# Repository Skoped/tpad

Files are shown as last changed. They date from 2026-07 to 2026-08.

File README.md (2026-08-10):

```                                                                                                                                           __                              .___
_/  |_          ___________     __| _/
\   __\  ______ \____ \__  \   / __ | 
 |  |   /_____/ |  |_> > __ \_/ /_/ | 
 |__|           |   __(____  /\____ | 
                |__|       \/      \/                                                                                                                                            
```
<sub> just a hackpad but better </sub>

so im made this macropad as a challenge, and it did NOT go well.
made this repo to show yall my progress   <sub> (its only made to submit this project) </sub>    i also couldnt make the knob work because i originally had the wrong 3d model for the rotary encoder.. (i made the knob :D)
anyways ignore all that,
# features.
it has 6 keys, one of them acting as a gateway to the second layer. so it technically has the usage of 10 keys, which i put from f1 to f10 because i use a 60% keyboard and the f-row doesnt always work for some reason.
it has a knob that acts as a way to decrease/increase volume, and when that knob is toggled, it acts as a way to decrease/increase brightness.
the screen currently only shows what layer your mini keyboard is on, pretty useless but im gonna work on another usecase.
# the pcb.
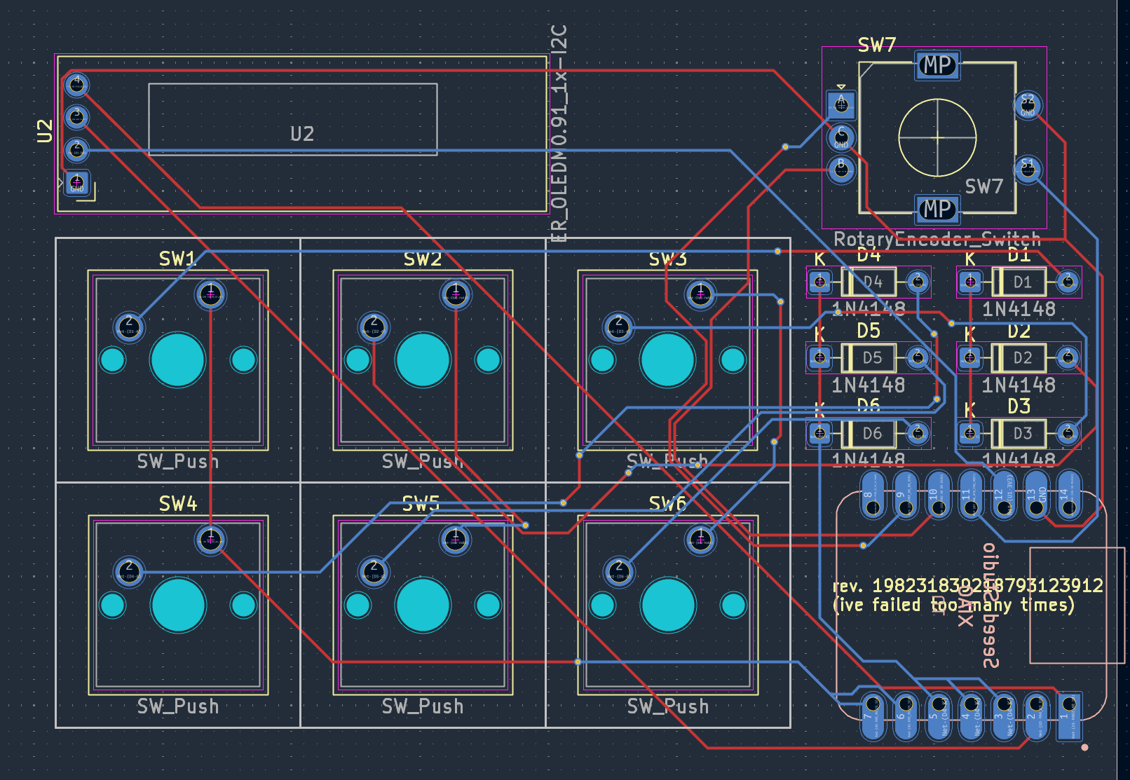
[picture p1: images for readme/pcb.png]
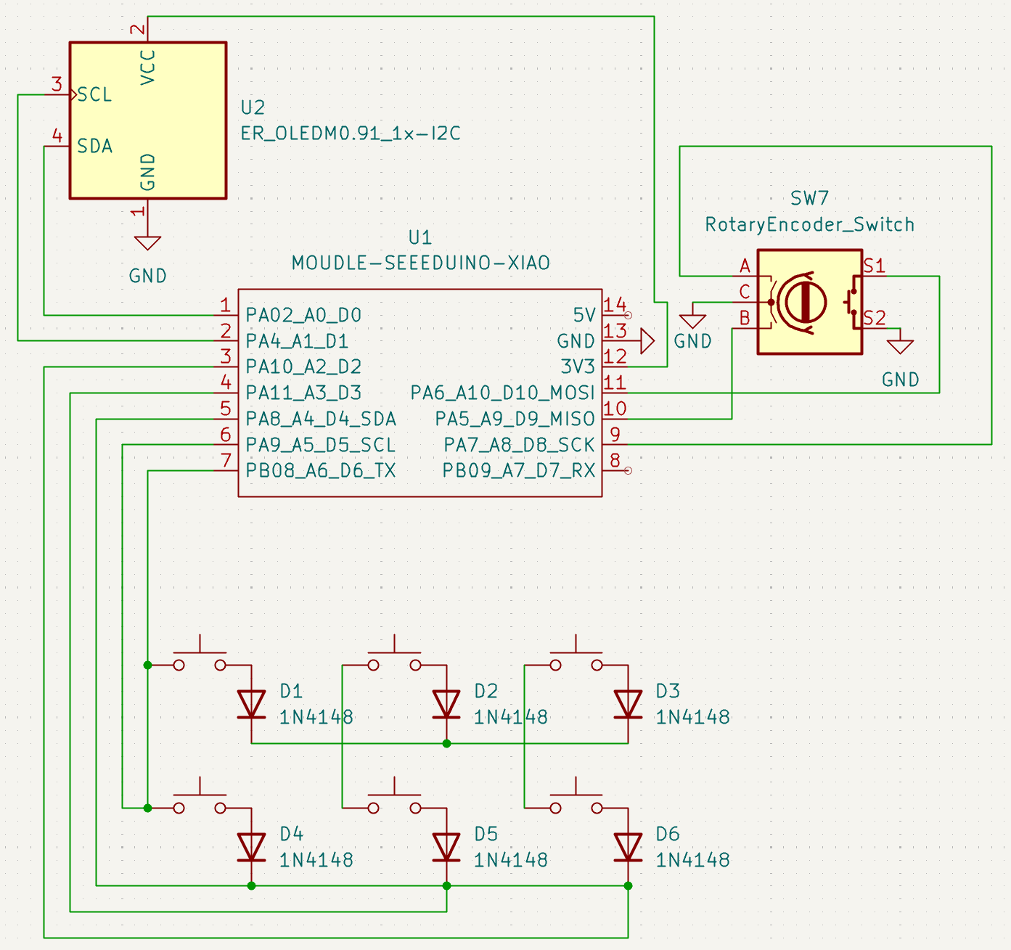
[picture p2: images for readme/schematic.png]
<figure> <figcaption>the pcb</figcaption>  </figure> <figure> <figcaption>the schematics</figcaption>  </figure>

i made this thing using kicad and tried to make it as tidy as possible which obviously i failed at that. this was probably the easiest part but i kept going back to it because i really didnt do it correctly at first.
# the case.
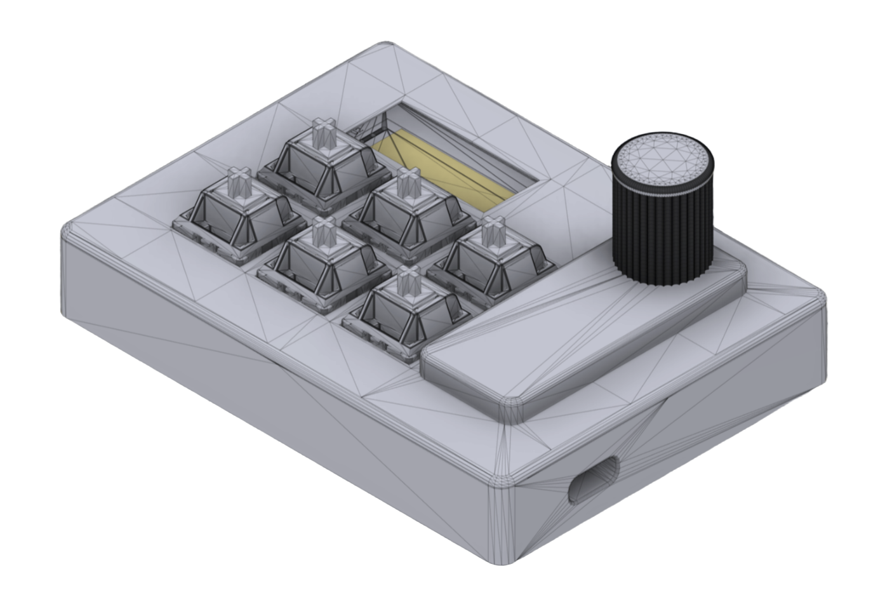
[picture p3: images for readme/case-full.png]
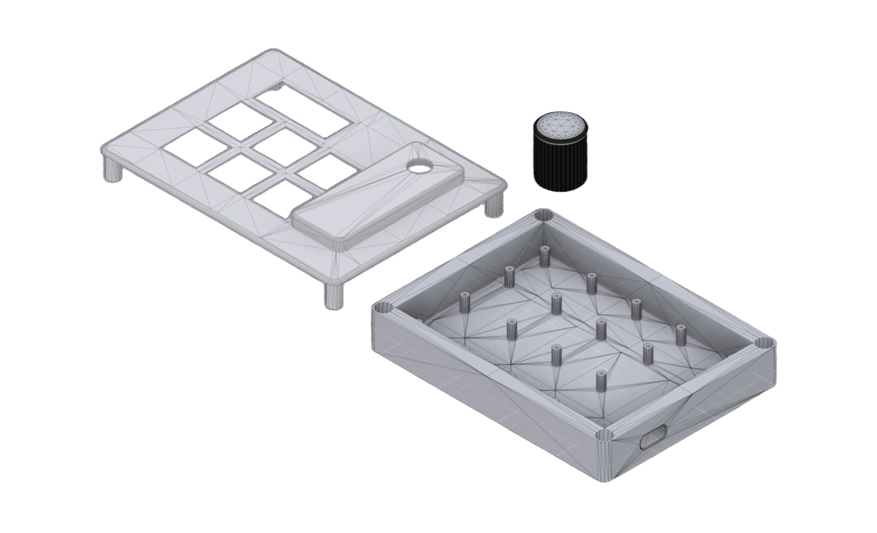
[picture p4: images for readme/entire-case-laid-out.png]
<figure> <figcaption>case put together</figcaption>  </figure> <figure> <figcaption>case laid out</figcaption>  </figure>

the case consists of 2 parts, the top and the bottom. i made it so the screws can screw in from the bottom, so that they can be hidden. the top has some columns coming out of it so the screw can screw the screw in the columns through the holes in the bottom layer, holding the two parts together.
worst part of this entire thing, fusion360 was too hard and i decided to experiment a bit with different software. i went on an ipad and found the absolute best app for this (very expensive so i used the trial :D). the app is shapr3d, i couldnt use fusion mostly because im using it on a pc with no touchscreen, making it harder to design what i wanted exactly.
# the firmware.
wasnt hard, kmk is easy and has alot of documentation to help with it. hopefully i can someday be good enough at programming to make a gui interface for remapping the keys. i only used layers to add about double the functionality to the keyboard (sixth button changes the entire keymap, and when the knob is pressed it changes brightness instead of volume, i just thought it was a cool way to make this different)
# BOM.
6x Cherry MX Switches

6x through-hole 1N4148 diodes

1x Seeed Studios XIAO RP2040

1x 0.91" OLED display SSD1306

1x EC11 rotary encoder

4x Keycaps

4x M3x5x4 headset inserts

4x M3x16mm screws

1x Case (2 part build, top and bottom)

### dont recommend this but will definitely do it again. 0/10
 *pcb and schematics made in kicad, case made in shapr3d, and the firmware made using kmk*

 this is not over, the screen basically doesnt do anything (just shows current keyboard layer) currently so im looking forward to edit its usecase. i also really wanna make that gui app for remapping everything :D

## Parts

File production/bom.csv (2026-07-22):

Designator | Footprint | Quantity | Value | LCSC Part #
D1, D2, D3, D4, D5, D6 | D_DO-35_SOD27_P7.62mm_Horizontal | 6 | 1N4148
SW1, SW2, SW3, SW4, SW5, SW6 | SW_Cherry_MX_1.00u_PCB | 6 | SW_Push
SW7 | RotaryEncoder_Alps_EC11E-Switch_Vertical_H20mm | 1 | RotaryEncoder_Switch
U1 | XIAO-Generic-Hybrid-14P-2.54-21X17.8MM | 1 | MOUDLE-SEEEDUINO-XIAO
U2 | ER_OLEDM0.91_1x-I2C | 1 | ER_OLEDM0.91_1x-I2C

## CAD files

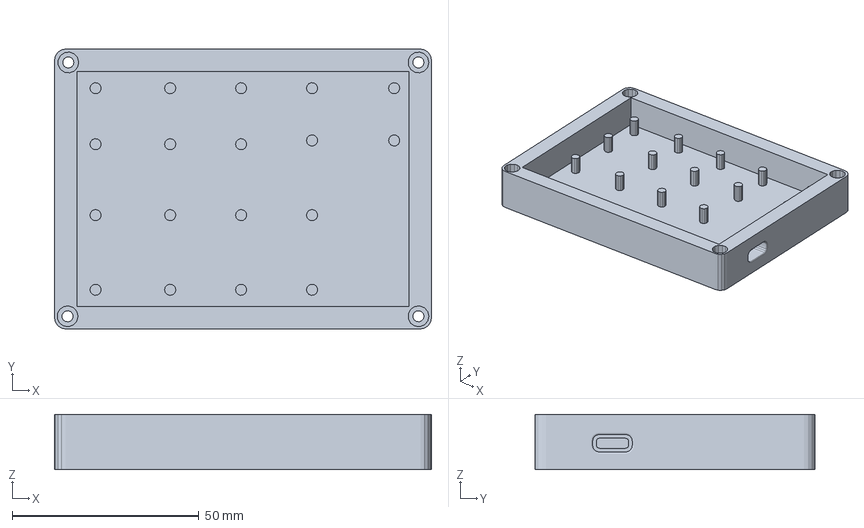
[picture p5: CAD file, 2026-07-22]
CAD/tpad-case.3mf
101.0 x 75.0 x 14.8 mm

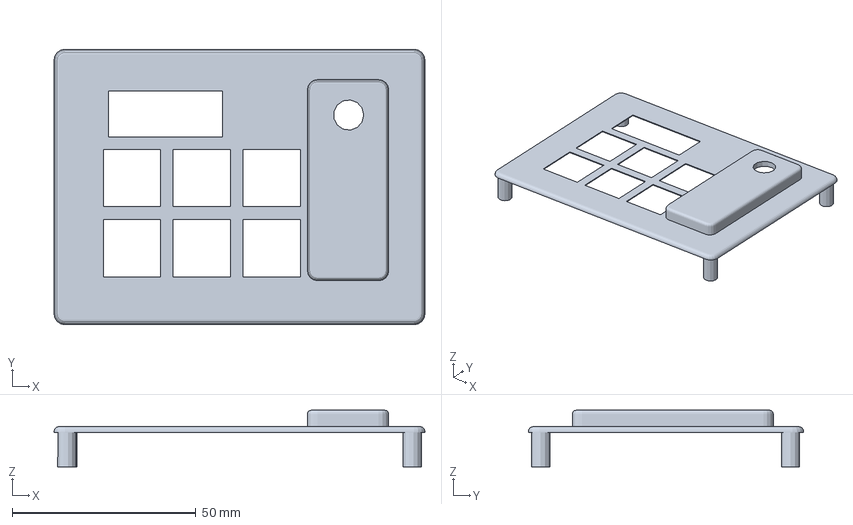
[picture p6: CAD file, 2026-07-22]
CAD/tpad-top.3mf
101.0 x 75.0 x 15.4 mm

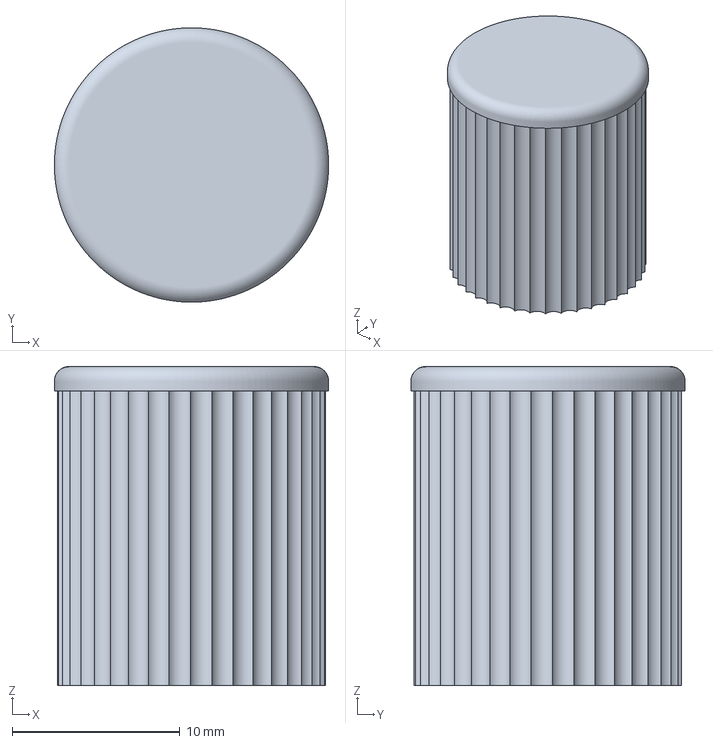
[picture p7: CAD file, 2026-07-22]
CAD/tpad-knob.3mf
16.3 x 16.3 x 19.0 mm

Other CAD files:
production/bottom.stl
production/top.stl

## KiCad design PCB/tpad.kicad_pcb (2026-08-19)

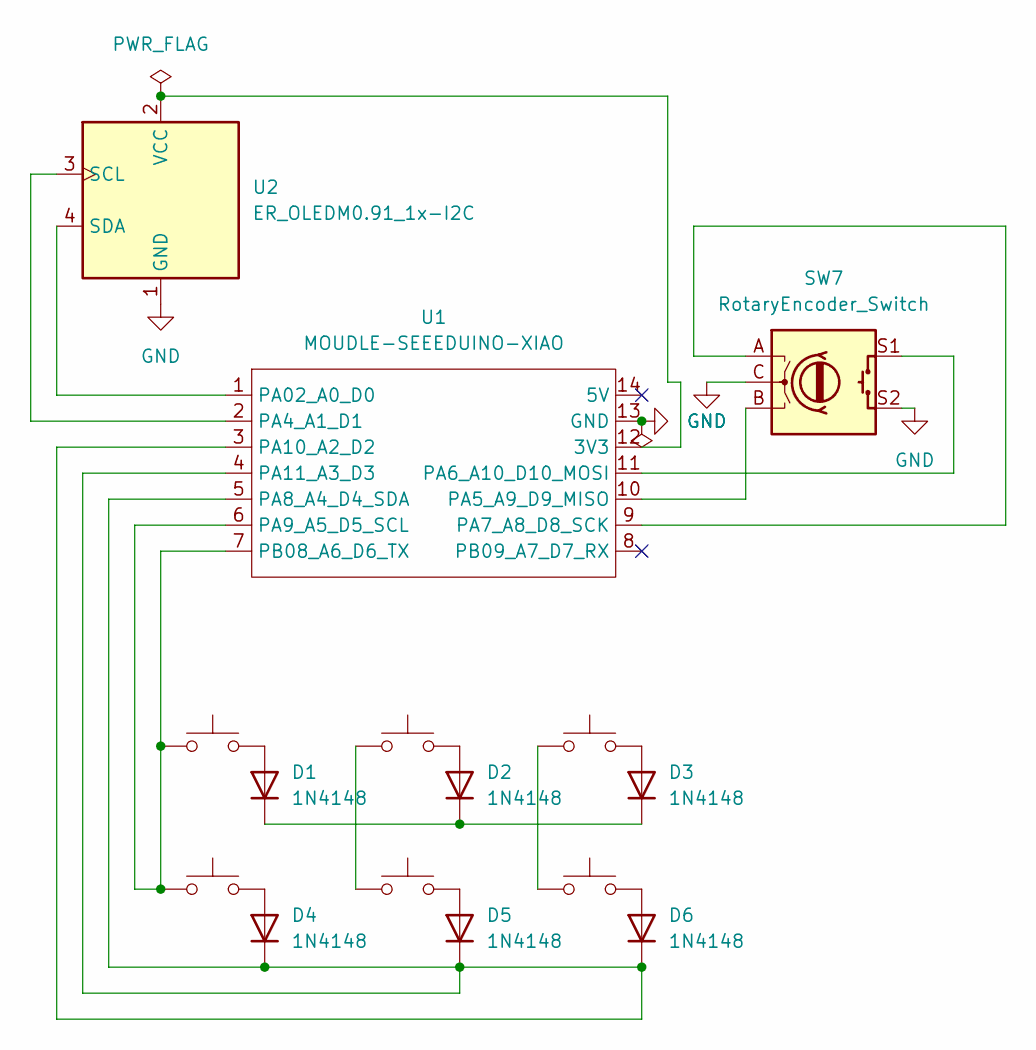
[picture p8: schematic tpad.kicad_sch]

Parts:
D1, D2, D3, D4, D5, D6: 1N4148; D_DO-35_SOD27_P7.62mm_Horizontal
SW1, SW2, SW3, SW4, SW5, SW6: SW_Push; SW_Cherry_MX_1.00u_PCB
SW7: RotaryEncoder_Switch; RotaryEncoder_Alps_EC11E-Switch_Vertical_H20mm
U1: MOUDLE-SEEEDUINO-XIAO; XIAO-Generic-Hybrid-14P-2.54-21X17.8MM
U2: ER_OLEDM0.91_1x-I2C

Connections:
GND: SW7.C, SW7.S2, U1.13 (GND), U2.1 (GND)
unnamed: D1.2 (A), SW1.2
unnamed: D1.1 (K), D2.1 (K), D3.1 (K)
unnamed: D2.2 (A), SW2.2
unnamed: D3.2 (A), SW3.2
unnamed: D4.2 (A), SW4.2
unnamed: D4.1 (K), D5.1 (K), D6.1 (K), U1.3 (PA10_A2_D2), U1.4 (PA11_A3_D3), U1.5 (PA8_A4_D4_SDA)
unnamed: D5.2 (A), SW5.2
unnamed: D6.2 (A), SW6.2
unnamed: SW2.1, SW5.1
unnamed: SW3.1, SW6.1
unnamed: U1.12 (3V3), U2.2 (VCC)
unnamed: U1.1 (PA02_A0_D0), U2.4 (SDA)
unnamed: U1.2 (PA4_A1_D1), U2.3 (SCL)
unnamed: SW7.B, U1.10 (PA5_A9_D9_MISO)
unnamed: SW7.S1, U1.11 (PA6_A10_D10_MOSI)
unnamed: SW7.A, U1.9 (PA7_A8_D8_SCK)
unnamed: SW1.1, SW4.1, U1.6 (PA9_A5_D5_SCL), U1.7 (PB08_A6_D6_TX)

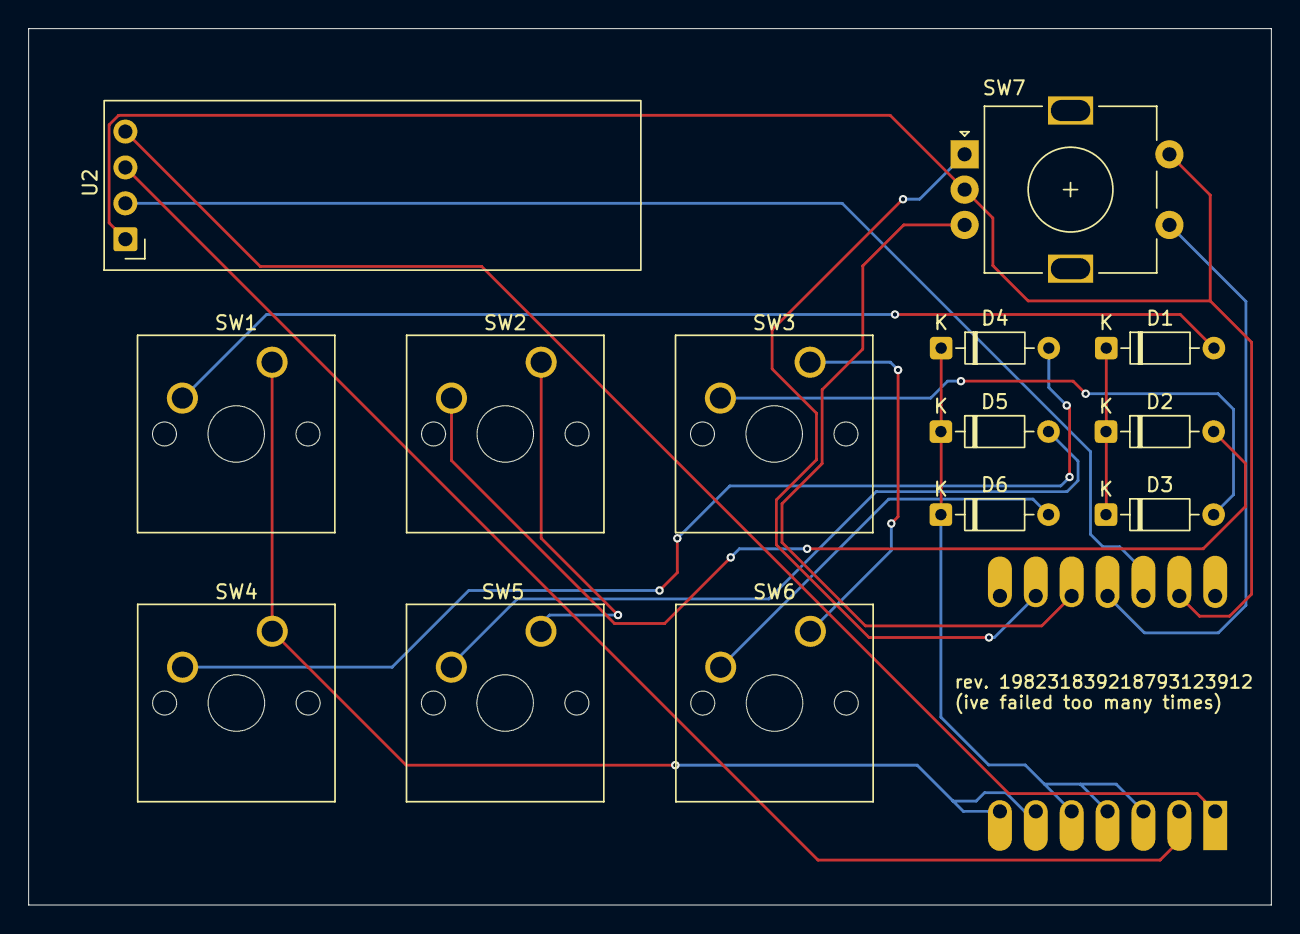
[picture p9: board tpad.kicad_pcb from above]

Board: 2 copper layers, 88.0 x 62.1 mm, 15 parts (1 on the bottom side), 18 nets.

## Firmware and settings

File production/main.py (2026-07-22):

import board
import busio

from kmk.kmk_keyboard import KMKKeyboard
from kmk.keys import KC
from kmk.scanners import DiodeOrientation
from kmk.modules.layers import Layers
from kmk.extensions.media_keys import MediaKeys
from kmk.extensions.display import Display, TextEntry
from kmk.extensions.display.ssd1306 import SSD1306
from kmk.modules.encoder import EncoderHandler

keyboard = KMKKeyboard()

#--key matrix--
keyboard.col_pins = (board.GP5, board.GP4, board.GP3)
keyboard.row_pins = (board.GP7, board.GP6)
keyboard.diode_orientation = DiodeOrientation.COL2ROW

#--modules for layers and rotary encoders--
layers = Layers()
encoder_handler = EncoderHandler()
keyboard.modules = [layers, encoder_handler]

encoder_handler.pins = (
    (board.GP9, board.GP10, board.GP11),
)

#--extensions for media keys and oled--
keyboard.extensions.append(MediaKeys())

i2c = busio.I2C(scl=board.GP2, sda=board.GP1)
display_driver = SSD1306(i2c=i2c, device_address=0x3C)

display = Display(
    display=display_driver,
    width=128,
    height=32,
    entries=[
        TextEntry(text='Layer 0', x=4, y=16, y_anchor='M', layer=0),
        TextEntry(text='Layer 1', x=4, y=16, y_anchor='M', layer=1)
    ],
)
keyboard.extensions.append(display)

#--keymap--
keyboard.keymap = [
     #layer0 keymap before pressing key 6
        [KC.F1, KC.F2, KC.F3, KC.F4, KC.F5, KC.MO(1)],
        [KC.F6, KC.F7, KC.F8, KC.F9, KC.F10, KC.TRNS],
]

#--rotary encoder stuff--
encoder_handler.map = [
    ((KC.VOLD, KC.VOLU, KC.TG(1)),), #when knob isnt not held
    ((KC.BRID, KC.BRIU, KC.TRNS),), #when knob is held
]

if __name__ == '__main__':
    keyboard.go()

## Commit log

2026-07-22 added files for the entire project
    [tpad-case.3mf, tpad-knob.3mf, tpad-top.3mf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]
2026-07-22 Add BOM section to README
    Added a Bill of Materials (BOM) section to the README, listing components used in the project.
2026-07-22 Update README with additional images
    Added schematic and case images to README.
2026-07-22 Revise README for better content structure
    Updated README.md to improve clarity and organization of content, including descriptions of the PCB, case, and firmware.
2026-07-22 Enhance README with updated images and details
    Updated images and descriptions for the PCB, case, and firmware sections. Improved layout and added details about the case design and software used.
2026-07-22 Enhance README with images and detailed descriptions
    Updated README.md to include additional images and descriptions for the PCB and case sections.
2026-07-22 added a dot to the BOM because why not
2026-07-22 readded production files
    [bom.csv, bottom.stl, top.stl]
2026-08-09 updates pcb files :)
    [tpad.kicad_pcb, tpad.kicad_sch]
2026-08-19 update pcb files yet again
    [tpad.kicad_pcb]
2026-08-19 update gerbers.zip :)
